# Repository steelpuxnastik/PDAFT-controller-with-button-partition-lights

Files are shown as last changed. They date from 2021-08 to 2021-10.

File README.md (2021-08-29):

# PDAFT controller with button/partition lights

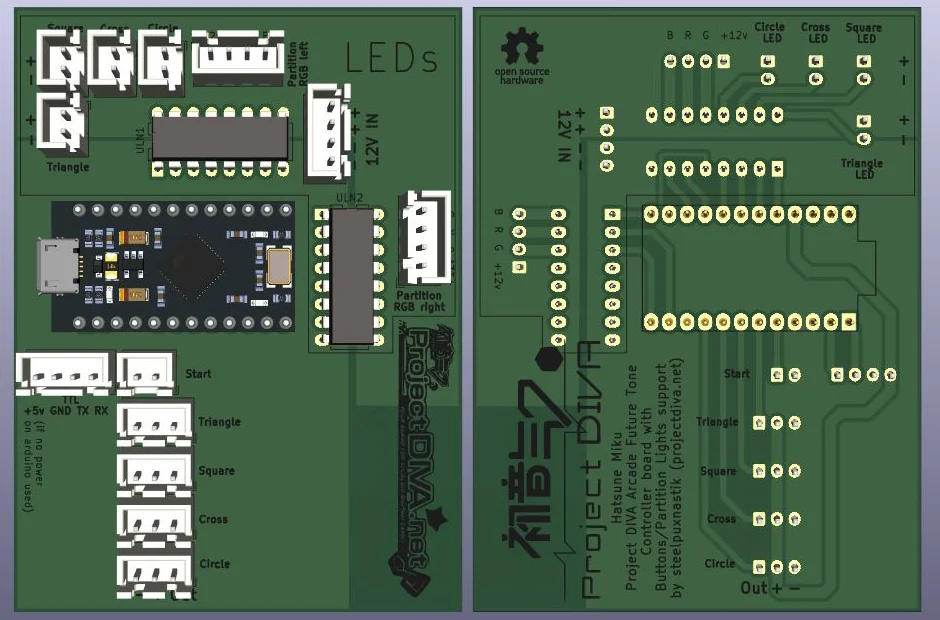
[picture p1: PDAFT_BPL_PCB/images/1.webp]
front


## What is it?
Hatsune Miku Project DIVA Arcade Future Tone controller with button/partition lights support (works fully like on official arcade machine) controlled by game. Controller realizes work with buttons (TRIANGLE, SQUARE, CROSS, CIRCLE, START) and abitily to connect 4 buttons LED and left/right partition 12V RGB LED strip (without slider, for slider I recomend to use LKP https://github.com/Project-Alpaca/LKP). LED info obtained by UART, special PD-Loader plugin activation needed (coming soon).

## Repository contains
Contains [PCB](/PDAFT_BPL_PCB) (KiCad 5.99+  (5.99.0-11737-gca42f31bb5), release build or newer needs to open) and [firmware](/firmware) for Arduino Pro Micro that used in it (use Arduino IDE 1.8 or newer to flash firmware).

## Variations
Board has two possibilities to receive serial data: throught USB (serial) or using TTL (serial1).
Why is that? Because ATMEGA32U4 chip directly supports USB connections and supports USB-Serial connection, but USB-Serial doesn't supports interuptions. Interuptions can be realized only throught direct connection to RX/TX pins using, for example, USB-TTL converter. It theoreticaly can make using gamepad without delays and Serial1 will be used only when new data will appear, but in real work with Serial data optimized as far as I know at this moment and works very fast (direct write to registers used), so needs only few cycles to work with that, so in reality maybe there will be no difference in use USB-Serial or TTL.

To use USB-Serial connection flash `firmware/firmware_USB-Serial/firmware_USB-Serial.ino`

To use TTL - `firmware/firmware_TTL/firmware_TTL.ino`

## Parts needed to use

`PDAFT_BPL_PCB` (1 pcs, order on JLCPCB or somewhere else or make it by yourself)

`JST XH 2pin socket and plug` (5 pcs) for:
  - Start button (desctibed pins from 1 to last, `OUT`, `GND`)
  - Triangle button LED (`+`, `-`)
  - Square button LED (`+`, `-`)
  - Cross button LED (`+`, `-`)
  - Circle button LED (`+`, `-`)

`JST XH 3pin socket and plug` (4 pcs) for:
  - Triangle button (`OUT`, `+` , `-`)
  - Square button (`OUT`, `+` , `-`)
  - Cross button (`OUT`, `+` , `-`)
  - Circle button (`OUT`, `+` , `-`)

`JST XH 4pin socket and plug` (4 pcs)
  - Partition RGB Left (`+12v`, `G`, `R`, `B`)
  - Partition RGB Right (`+12v`, `G`, `R`, `B`)
  - TTL (`RX`, `TX`, `GND`, `+5v`. Do not use 4 pin `+5V` if you connect Arduino with USB)
  - 12V IN (`+`, `+`, `-`,`-`. JST XH connection by datasheet has 3A current rating limitation on one pin, if you'll use long stripes with a lot of LEDs, most likely current will be somewhere around or more then 3A, so better to make paralelized connection to board with two 22 AWG or thicker wire for `12V` (`+`) and `GND` (`-`) from the power socket to board. *I'll uploud picture later about that for you to understand*)
  
 `Arduino ProMicro` (1 pcs)
 
 `12 pin header` (2 pcs, to have possibility to just plug in Arduino ProMicro and change it if needed without soldering, `12 pin header` will be soldered)
 
 `ULN2003` (2 pcs, to use LEDs with it)
 
 `DIP 16 pin socket` (2 pcs, to make possibility to change `ULN2003` without soldering if needed, `DIP 16 pin socket` will be soldered)
 
 `22 AWG wires` (can be found on aliexpress, I recommend to grab more 5 pin 22 AWG white-blue-red-green-black cable, if you use [SHINSANWASWITCH](https://github.com/steelpuxnastik/SHINSANWASWITCH) it will be usefull too)

## About button connection

By default assumed that you will connect active optical switches ([SHINSANWASWITCH](https://github.com/steelpuxnastik/SHINSANWASWITCH) or OBSA-LHSXF-LN or other) as Triangle, Square, Cross, Circle buttons. If you want to connect passive switches - use connection only to 1 pin (`OUT`) and 3 pin (`-`) and connect nothing to 2 pin (`+`).

## Work in progress

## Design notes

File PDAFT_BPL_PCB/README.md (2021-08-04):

KICAD Version: (5.99.0-11575-g46338403e7), release build or newer needed to open files

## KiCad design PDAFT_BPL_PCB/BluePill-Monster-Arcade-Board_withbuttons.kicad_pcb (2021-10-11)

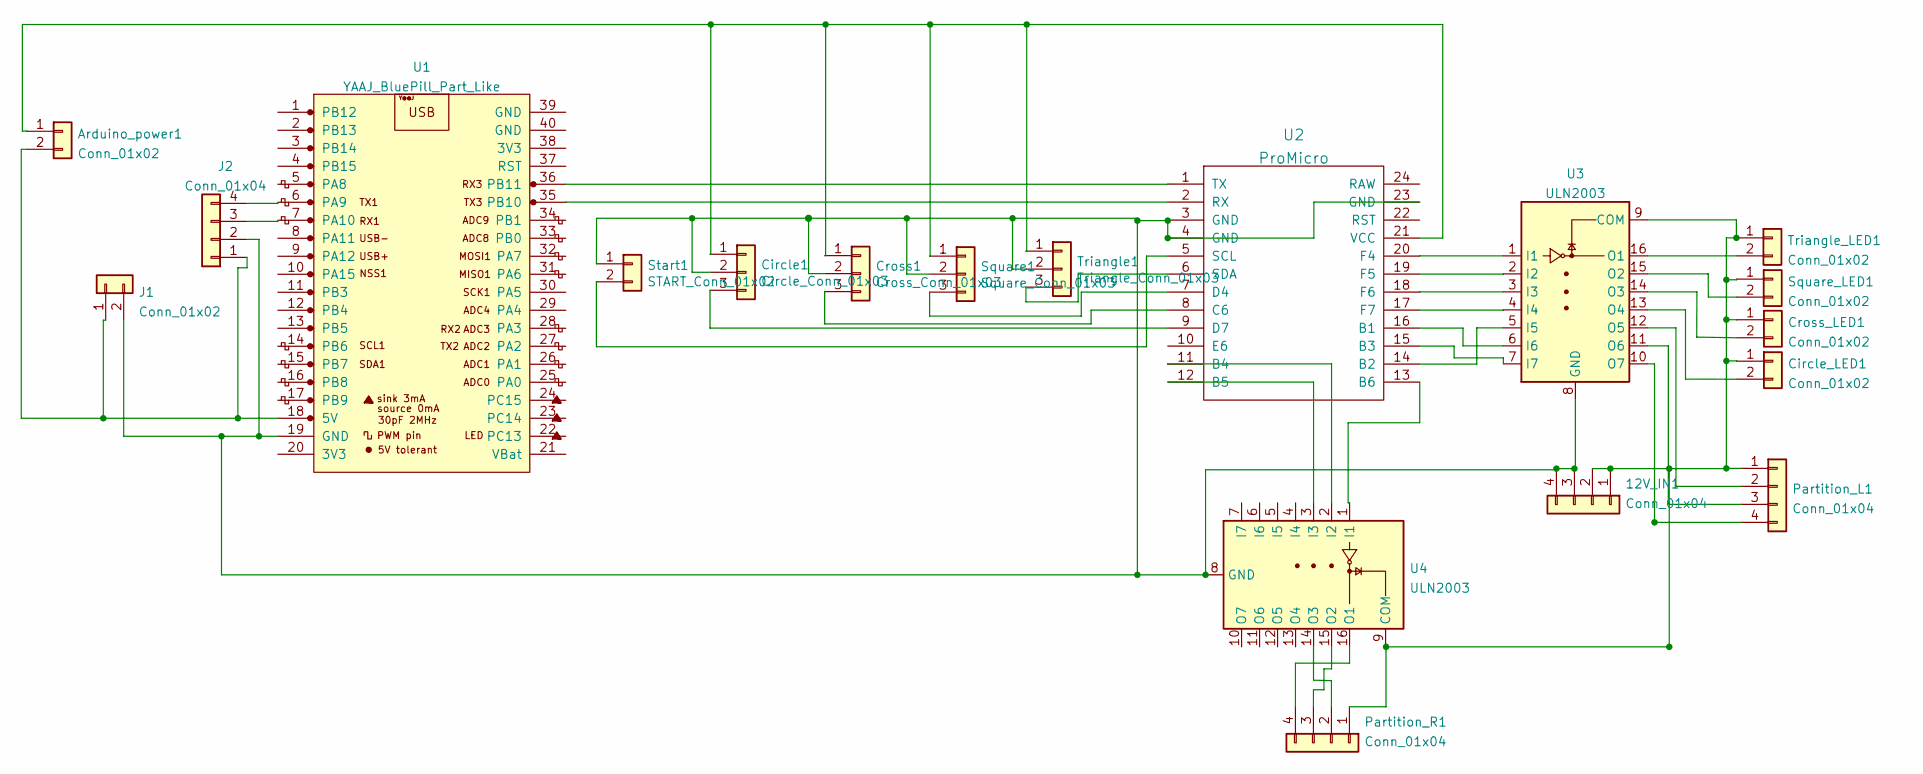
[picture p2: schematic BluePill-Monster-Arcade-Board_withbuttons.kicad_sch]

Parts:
12V_IN1: Conn_01x04; JST_XH_B4B-XH-A_1x04_P2.50mm_Vertical
Arduino_power1: Conn_01x02; JST_XH_B2B-XH-A_1x02_P2.50mm_Vertical
Circle1: Circle_Conn_01x03; JST_XH_B3B-XH-A_1x03_P2.50mm_Vertical
Circle_LED1: Conn_01x02; JST_XH_B2B-XH-A_1x02_P2.50mm_Vertical
Cross1: Cross_Conn_01x03; JST_XH_B3B-XH-A_1x03_P2.50mm_Vertical
Cross_LED1: Conn_01x02; JST_XH_B2B-XH-A_1x02_P2.50mm_Vertical
J1: Conn_01x02; JST_XH_B2B-XH-A_1x02_P2.50mm_Vertical
J2: Conn_01x04; JST_XH_B4B-XH-A_1x04_P2.50mm_Vertical
Partition_L1: Conn_01x04; JST_XH_B4B-XH-A_1x04_P2.50mm_Vertical
Partition_R1: Conn_01x04; JST_XH_B4B-XH-A_1x04_P2.50mm_Vertical
Square1: Square_Conn_01x03; JST_XH_B3B-XH-A_1x03_P2.50mm_Vertical
Square_LED1: Conn_01x02; JST_XH_B2B-XH-A_1x02_P2.50mm_Vertical
Start1: START_Conn_01x02; JST_XH_B2B-XH-A_1x02_P2.50mm_Vertical
Triangle1: Triangle_Conn_01x03; JST_XH_B3B-XH-A_1x03_P2.50mm_Vertical
Triangle_LED1: Conn_01x02; JST_XH_B2B-XH-A_1x02_P2.50mm_Vertical
U1: YAAJ_BluePill_Part_Like; YAAJ_BluePill_1
U2: ProMicro
U3, U4: ULN2003; DIP-16_W7.62mm

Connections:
unnamed: 12V_IN1.1, 12V_IN1.2, Circle_LED1.1, Cross_LED1.1, Partition_L1.1, Partition_R1.1, Square_LED1.1, Triangle_LED1.1, U3.9 (COM), U4.9 (COM)
unnamed: 12V_IN1.3, 12V_IN1.4, Circle1.2, Cross1.2, J1.2, J2.2, Square1.2, Start1.1, Triangle1.2, U1.19 (GND), U2.3 (GND), U2.4 (GND), U2.23 (GND), U3.8 (GND), U4.8 (GND)
unnamed: Arduino_power1.1, Circle1.1, Cross1.1, Square1.1, Triangle1.1, U2.21 (VCC)
unnamed: Arduino_power1.2, J1.1, J2.1, U1.18 (5V)
unnamed: Circle1.3, U2.9 (D7)
unnamed: Circle_LED1.2, U3.13 (O4)
unnamed: Cross1.3, U2.8 (C6)
unnamed: Cross_LED1.2, U3.14 (O3)
unnamed: J2.3, U1.7 (PA10)
unnamed: J2.4, U1.6 (PA9)
unnamed: Partition_L1.2, U3.12 (O5)
unnamed: Partition_L1.3, U3.11 (O6)
unnamed: Partition_L1.4, U3.10 (O7)
unnamed: Partition_R1.2, U4.14 (O3)
unnamed: Partition_R1.3, U4.15 (O2)
unnamed: Partition_R1.4, U4.16 (O1)
unnamed: Square1.3, U2.7 (D4)
unnamed: Square_LED1.2, U3.15 (O2)
unnamed: Start1.2, U2.5 (SCL)
unnamed: Triangle1.3, U2.6 (SDA)
unnamed: Triangle_LED1.2, U3.16 (O1)
unnamed: U1.35 (PB10), U2.2 (RX)
unnamed: U1.36 (PB11), U2.1 (TX)
unnamed: U2.11 (B4), U4.2 (I2)
unnamed: U2.12 (B5), U4.3 (I3)
unnamed: U2.13 (B6), U4.1 (I1)
unnamed: U2.14 (B2), U3.5 (I5)
unnamed: U2.15 (B3), U3.7 (I7)
unnamed: U2.16 (B1), U3.6 (I6)
unnamed: U2.17 (F7), U3.4 (I4)
unnamed: U2.18 (F6), U3.3 (I3)
unnamed: U2.19 (F5), U3.2 (I2)
unnamed: U2.20 (F4), U3.1 (I1)

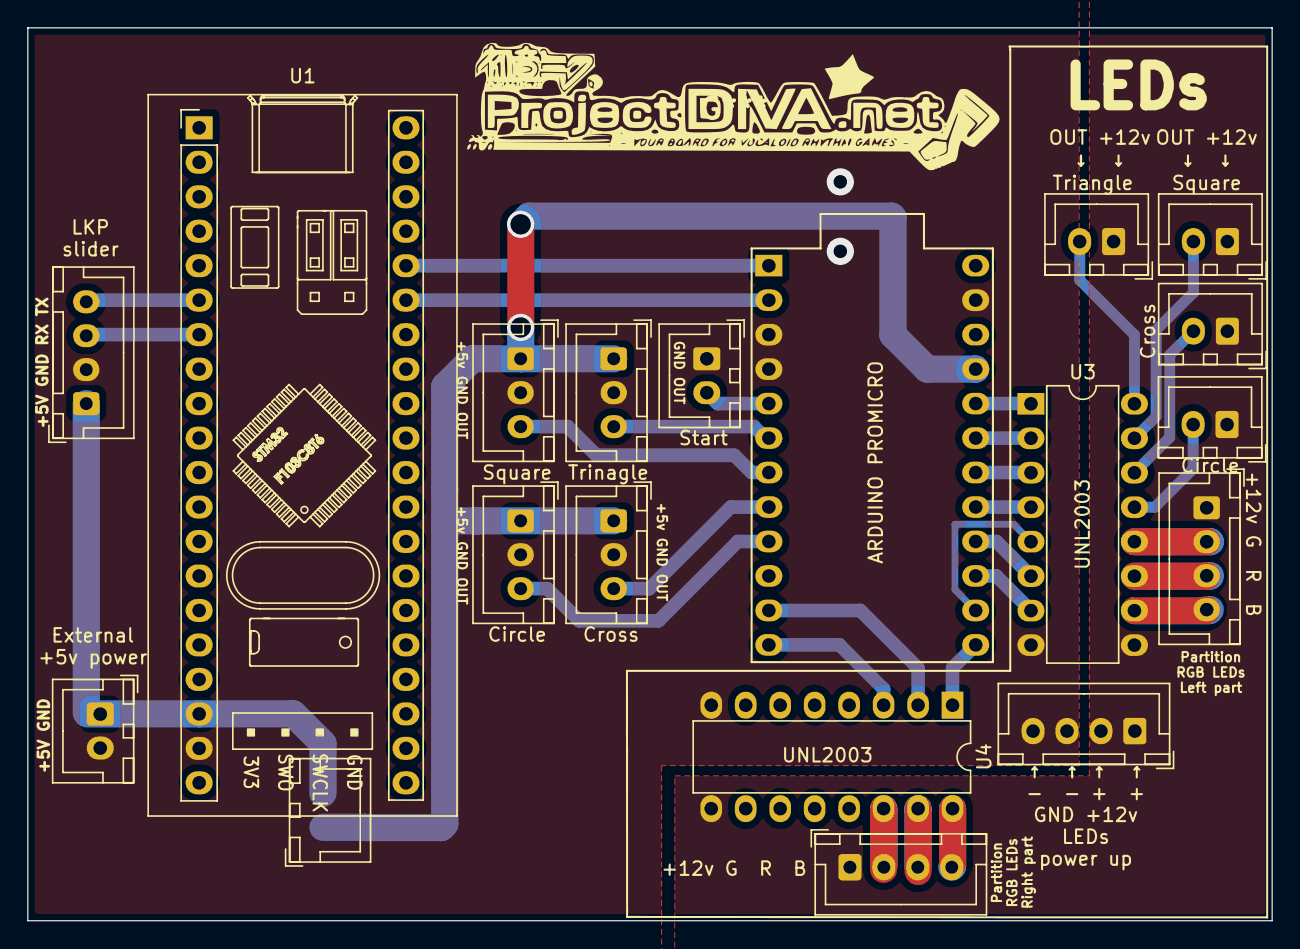
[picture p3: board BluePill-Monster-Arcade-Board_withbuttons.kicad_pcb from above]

Board: 2 copper layers, 91.7 x 65.8 mm, 19 parts (0 on the bottom side), 33 nets.

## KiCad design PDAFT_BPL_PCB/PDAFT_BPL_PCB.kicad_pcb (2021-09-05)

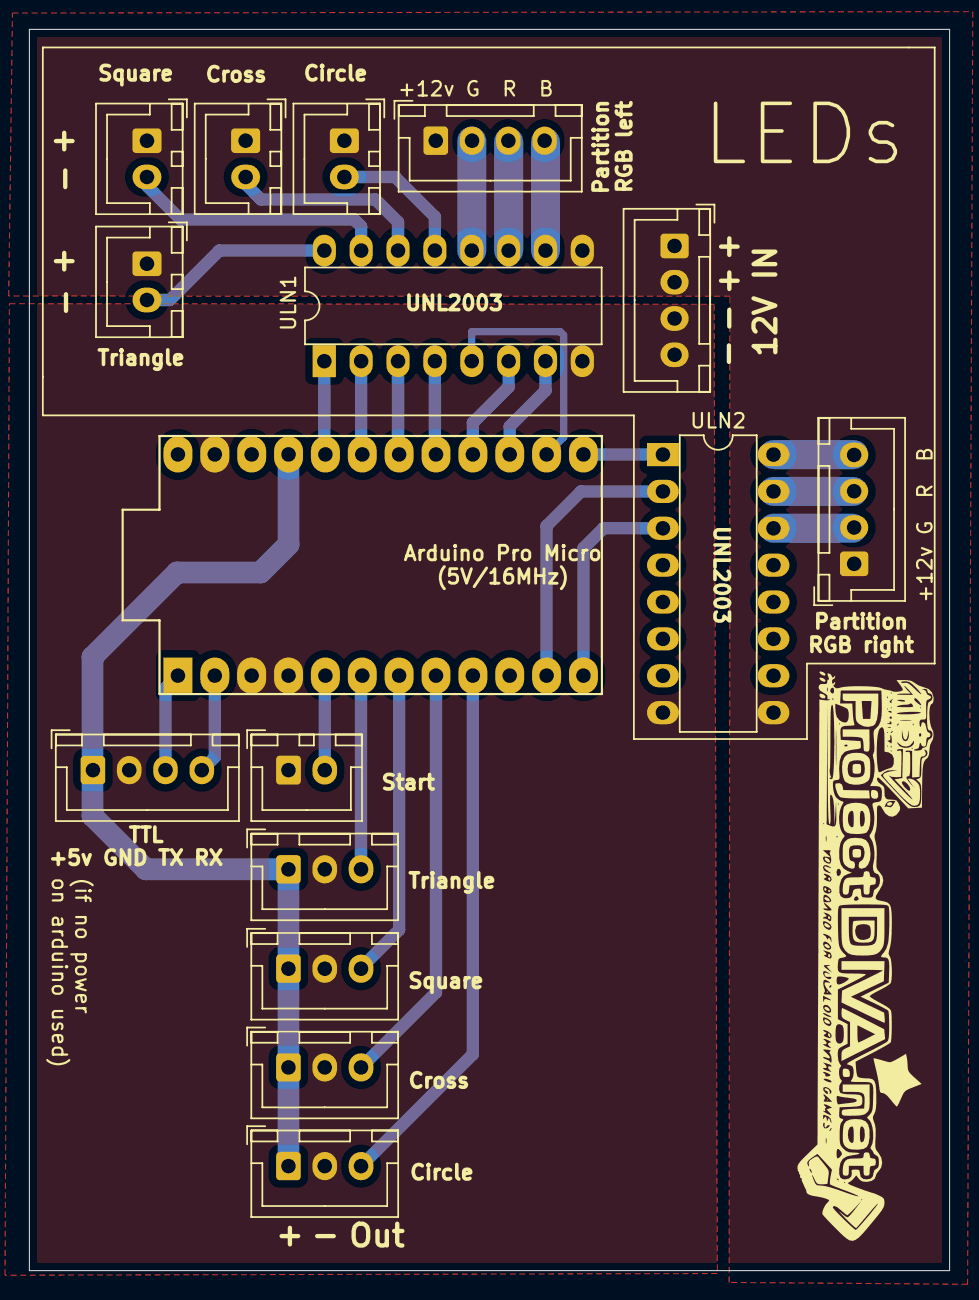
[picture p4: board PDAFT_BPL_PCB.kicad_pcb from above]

Board: 2 copper layers, 63.4 x 85.5 mm, 16 parts (0 on the bottom side), 30 nets.

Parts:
12V_IN1: 12V_IN; JST_XH_B4B-XH-A_1x04_P2.50mm_Vertical
CIRCLE_LED1: CIRCLE_LED_Conn_01x02; JST_XH_B2B-XH-A_1x02_P2.50mm_Vertical
CROSS_LED1: CROSS_LED_Conn_01x02; JST_XH_B2B-XH-A_1x02_P2.50mm_Vertical
Circle1: Circle_Conn_01x03; JST_XH_B3B-XH-A_1x03_P2.50mm_Vertical
Cross1: Cross_Conn_01x03; JST_XH_B3B-XH-A_1x03_P2.50mm_Vertical
Partition_L1: Conn_01x04; JST_XH_B4B-XH-A_1x04_P2.50mm_Vertical
Partition_R1: Conn_01x04; JST_XH_B4B-XH-A_1x04_P2.50mm_Vertical
ProMicro1: ProMicro
SQUARE_LED1: SQUARE_LED_Conn_01x02; JST_XH_B2B-XH-A_1x02_P2.50mm_Vertical
Square1: Square_Conn_01x03; JST_XH_B3B-XH-A_1x03_P2.50mm_Vertical
Start1: START_Conn_01x02; JST_XH_B2B-XH-A_1x02_P2.50mm_Vertical
TRIANGLE_LED1: TRIANGLE_LED_Conn_01x02; JST_XH_B2B-XH-A_1x02_P2.50mm_Vertical
TTL1: Conn_01x04; JST_XH_B4B-XH-A_1x04_P2.50mm_Vertical
Triangle1: Triangle_Conn_01x03; JST_XH_B3B-XH-A_1x03_P2.50mm_Vertical
ULN1, ULN2: ULN2003; DIP-16_W7.62mm

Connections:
unnamed: 12V_IN1.1, 12V_IN1.2, CIRCLE_LED1.1, CROSS_LED1.1, Partition_L1.1, Partition_R1.1, SQUARE_LED1.1, TRIANGLE_LED1.1, ULN1.9 (COM), ULN2.9 (COM)
unnamed: 12V_IN1.3, 12V_IN1.4, Circle1.2, Cross1.2, ProMicro1.3 (GND), ProMicro1.4 (GND), ProMicro1.23 (GND), Square1.2, Start1.1, TTL1.2, Triangle1.2, ULN1.8 (GND), ULN2.8 (GND)
unnamed: CIRCLE_LED1.2, ULN1.13 (O4)
unnamed: CROSS_LED1.2, ULN1.14 (O3)
unnamed: Partition_L1.2, ULN1.12 (O5)
unnamed: Partition_L1.3, ULN1.11 (O6)
unnamed: Partition_L1.4, ULN1.10 (O7)
unnamed: Partition_R1.2, ULN2.14 (O3)
unnamed: Partition_R1.3, ULN2.15 (O2)
unnamed: Partition_R1.4, ULN2.16 (O1)
unnamed: ProMicro1.5 (SCL), Start1.2
unnamed: ProMicro1.6 (SDA), Triangle1.3
unnamed: ProMicro1.7 (D4), Square1.3
unnamed: Cross1.3, ProMicro1.8 (C6)
unnamed: Circle1.3, ProMicro1.9 (D7)
unnamed: ProMicro1.11 (B4), ULN2.2 (I2)
unnamed: ProMicro1.12 (B5), ULN2.3 (I3)
unnamed: ProMicro1.13 (B6), ULN2.1 (I1)
unnamed: ProMicro1.14 (B2), ULN1.5 (I5)
unnamed: ProMicro1.15 (B3), ULN1.7 (I7)
unnamed: ProMicro1.16 (B1), ULN1.6 (I6)
unnamed: ProMicro1.17 (F7), ULN1.4 (I4)
unnamed: ProMicro1.18 (F6), ULN1.3 (I3)
unnamed: ProMicro1.19 (F5), ULN1.2 (I2)
unnamed: ProMicro1.20 (F4), ULN1.1 (I1)
unnamed: Circle1.1, Cross1.1, ProMicro1.21 (VCC), Square1.1, TTL1.1, Triangle1.1
unnamed: SQUARE_LED1.2, ULN1.15 (O2)
unnamed: TRIANGLE_LED1.2, ULN1.16 (O1)
unnamed: ProMicro1.1 (TX), TTL1.3
unnamed: ProMicro1.2 (RX), TTL1.4

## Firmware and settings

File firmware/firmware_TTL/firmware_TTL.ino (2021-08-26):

#include <HID-Project.h>

#define arraySize 3
#define Sync 0xff

#define CIRCLE 3
#define CROSS 2
#define SQUARE 1
#define TRIANGLE 4
#define OPTION 10

#define CIRCLE_PIN 6
#define CROSS_PIN 5
#define SQUARE_PIN 4
#define TRIANGLE_PIN 3
#define START_PIN 2

/*#define led1 21  // BUTTON LED TRIANGLE
#define led2 20  // BUTTON LED SQUARE
#define led3 19  // BUTTON LED CROSS
#define led4 18  // BUTTON LED CIRCLE

#define led_R1 15  // LEFT PARTITION LED PED
#define led_G1 16  // LEFT PARTITION LED GREEN
#define led_B1 14  // LEFT PARTITION LED BLUE

#define led_R2 8  // RIGHT PARTITION LED PED
#define led_G2 9 // RIGHT PARTITION LED GREEN
#define led_B2 10 // RIGHT PARTITION LED BLUE*/

volatile uint8_t iteration = 0;
volatile uint8_t inData[arraySize];

#define BUTTON_NUM 5

const unsigned char button_direct_table[8] = {
  TRIANGLE, SQUARE, CROSS, CIRCLE, OPTION, 0, 0, 0
};

const unsigned char button_direct_logic = 0b11111110;

const int button_direct_pin_table[BUTTON_NUM] = {
  TRIANGLE_PIN, SQUARE_PIN, CROSS_PIN, CIRCLE_PIN, START_PIN
};

unsigned char button_data_byte = 0;

unsigned char readDirectlyConnectedButtons(int *pin_table, unsigned char pin_logic);
void addHIDreportFromTable(unsigned char serial_data_byte, unsigned char *button_table, int contents_of_table_num);

void setup(void) {
  //Serial.begin(115200);
  Serial1.begin(115200);
  DDRF = 0b11110000; //18 19 20 21 Button LEDs
  DDRB = 0b01111110; //8 9 10 14 15 16 Partition LEDs
  for(int i = 0; i < BUTTON_NUM; i++) {
    pinMode(button_direct_pin_table[i], INPUT_PULLUP);
  }
  Gamepad.begin();
}

void loop(void) {
  button_data_byte = readDirectlyConnectedButtons(button_direct_pin_table, button_direct_logic);
  addHIDreportFromTable(button_data_byte, button_direct_table, BUTTON_NUM);
  Gamepad.write();
  //serialUSB();
}

unsigned char readDirectlyConnectedButtons(int *pin_table, unsigned char pin_logic) {
  unsigned char result = 0;
  for(int i = 0; i < BUTTON_NUM; i++) {
    result |= (digitalRead(pin_table[i]) << (7 - i));
  }
  return result ^ pin_logic;
}

void addHIDreportFromTable(unsigned char serial_data_byte, unsigned char *button_table, int contents_of_table_num) {
  for(int i = 0; i < contents_of_table_num; i++)
    serial_data_byte >> (7 - i) & 0x01 ? Gamepad.press(button_table[i]) : Gamepad.release(button_table[i]);
}

void serialUSB(){
  inData[iteration] = Serial.read();
  iteration++;
  if(iteration>2) 
     Update();
  if(inData[0] != Sync) 
     Clear();
}

void serialEvent1(){
  inData[iteration] = Serial1.read();
  iteration++;
  if(iteration>2) 
     Update();
  if(inData[0] != Sync) 
     Clear();
}

void Update() {
//BUTTONS 
      PORTF = inData[1] << 4;

//SIDES
      PORTB = inData[2] << 1;
      
      Clear();
}
    
void Clear() {
      iteration = 0;
      inData[0] = 0;
      inData[1] = 0;
      inData[2] = 0;
}

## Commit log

2021-07-29 Kicad board and test firmware added
    [PDAFT_BPL_PCB.kicad_pcb, PDAFT_BPL_PCB.kicad_sch, PDAFT_BPL_PCB.sch]
2021-07-29 readme from old board detele :)
2021-07-30 Update PCB
    Update PCB to make fast write to registers in interruptions when received LEDs data by UART
    [PDAFT_BPL_PCB.kicad_pcb, PDAFT_BPL_PCB.kicad_sch]
2021-08-04 Update of PCB and firmware
    Updated PCB to have possibility to connect USB-TTL converter to use interuption in serial connection (program for it will be soon completed with various variants of use, now only SerialEvent1() inter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
    [PDAFT_BPL_PCB.kicad_pcb, PDAFT_BPL_PCB.kicad_sch]
2021-08-26 Added +5v from TTL to use if needed
    [PDAFT_BPL_PCB.kicad_pcb, PDAFT_BPL_PCB.kicad_sch]
2021-08-26 Changing 12vin JST XH2 to XH4
    Changing 12Vin JST XH2 to XH4 because of possible current rating limits 3A, so better to parallelize 12Vin to avoid problems with it
    [PDAFT_BPL_PCB.kicad_pcb, PDAFT_BPL_PCB.kicad_sch]
2021-08-26 Firmware update
    Firmware updated (USB-Serial and serial1 different firmware files), added 3D-model of Arduino for picture, pictures added, readme updated
    [PDAFT_BPL_PCB.kicad_pcb, PDAFT_BPL_PCB.kicad_sch]
2021-08-26 PCB update
    [PDAFT_BPL_PCB.kicad_pcb]
2021-08-27 Additional poligon on the top, other fixes
    [PDAFT_BPL_PCB.kicad_pcb]
2021-08-27 Holes correct
    [PDAFT_BPL_PCB.kicad_pcb]
2021-08-29 board update
    [PDAFT_BPL_PCB.kicad_pcb]
2021-09-03 Update for DIY-make
    [PDAFT_BPL_PCB.kicad_pcb]
2021-09-05 Added shorter variant, maybe later it will be main
    Also some elements optimization
    [PDAFT_BPL_PCB.kicad_pcb, PDAFT_BPL_PCB_shorter.kicad_pcb, PDAFT_BPL_PCB_shorter.kicad_sch]
2021-09-05 BluePill-moster added
    [BluePill-Monster-Arcade-Board_withbuttons.kicad_pcb, BluePill-Monster-Arcade-Board_withbuttons.kicad_sch, BluePill-Monster-Arcade-Board_withoutbuttons.kicad_pc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]
2021-09-05 bluepill update
    [BluePill-Monster-Arcade-Board_withbuttons.kicad_pcb, BluePill-Monster-Arcade-Board_withbuttons.kicad_sch]
2021-10-11 Update of bluepill moster with buttons to order on JLCPCB
    [BluePill-Monster-Arcade-Board_withbuttons.kicad_pcb, BluePill-Monster-Arcade-Board_withbuttons.kicad_sch]
